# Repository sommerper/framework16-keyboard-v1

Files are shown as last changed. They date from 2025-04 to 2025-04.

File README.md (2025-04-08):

# Framework 16 Keyboard v1

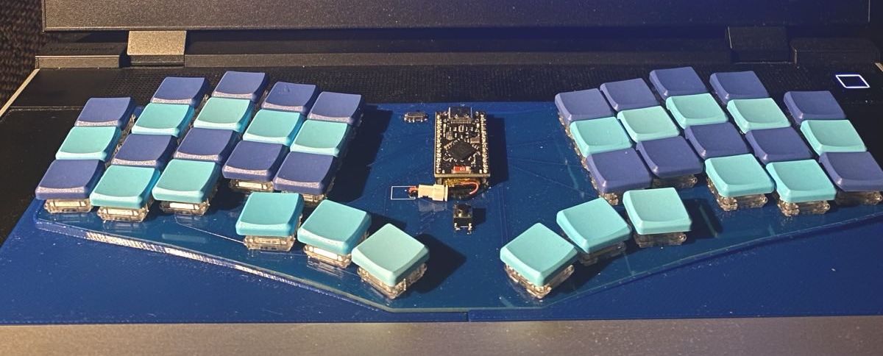
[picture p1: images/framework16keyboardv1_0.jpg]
Keyboard Image


Here's an ortholinear split keyboard that fits in your Framework 16 instead of the default keyboard.

It's using Kaihl Choc switches and the case has an angle of 5 degrees so it will not allow you to close the laptop while using it.

## ZMK and QMK

There some settings for zmk and qmk to get you started with the correct pin layout. The ZMK config is based on [Urob's config](https://github.com/urob/zmk-config)

Any Pro Micro compatible controller should work. The nice!nano v2 is used in the image, and I have also connected an RP2040 without any problems. 

## 3D Print Files
- Left and Right are for the laptop. They should have a tight fit without having to squeeze them in between the other components. 
- Bottom is for your desk so you can choose to put the pcb on your desk as well. It's possible to fit this on the build plate of a standard Prusa mk3s if you put it diagonally.
- Top is for travel protection. It fits on top of the Bottom case with the keyboard inside.

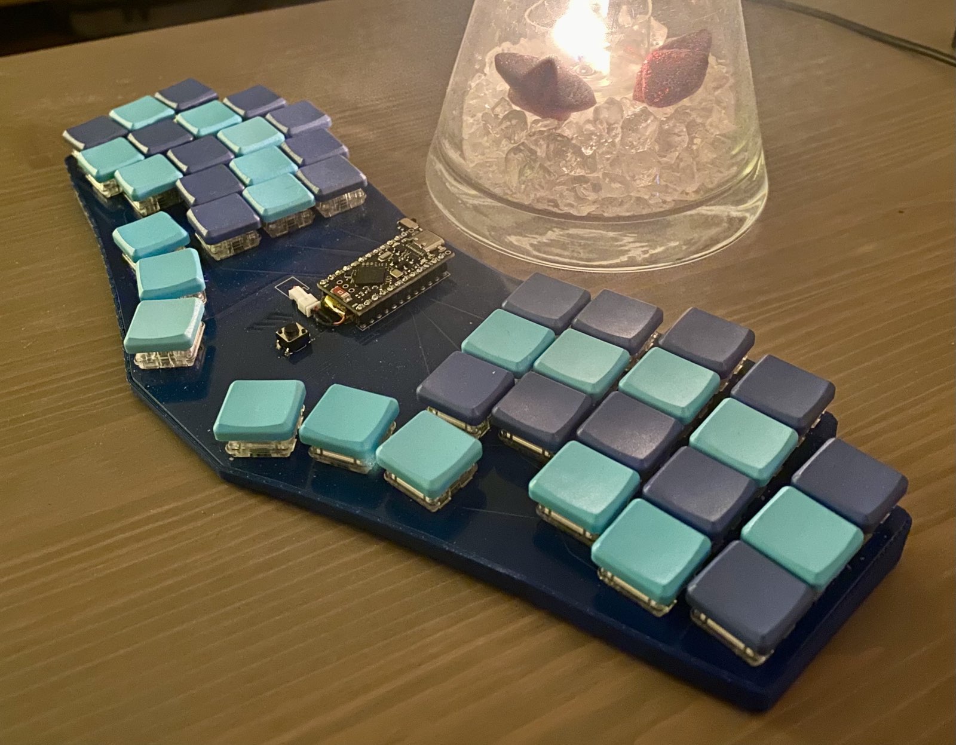
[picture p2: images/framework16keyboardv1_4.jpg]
Desk print


## ⚠️ Disclaimer

These PCB files are provided **as-is**, without any warranty or guarantee of functionality or safety. Use them at your own risk. I am not responsible for any damage, injury, or loss resulting from the use of these files.

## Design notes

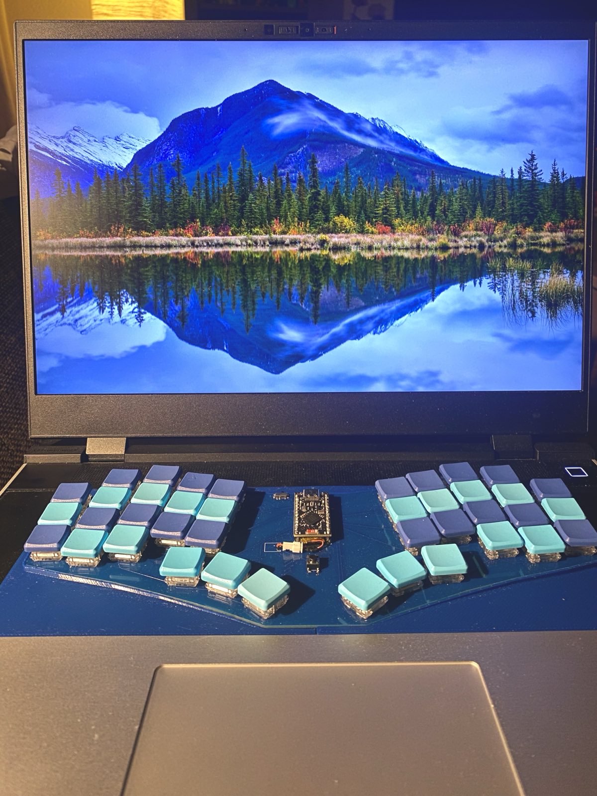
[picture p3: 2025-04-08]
images/framework16keyboardv1_1.jpg

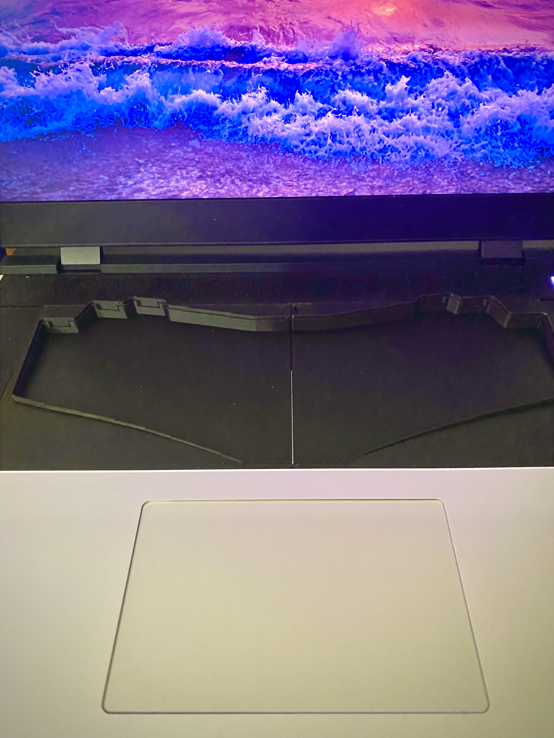
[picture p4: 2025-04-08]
images/framework16keyboardv1_3.jpg

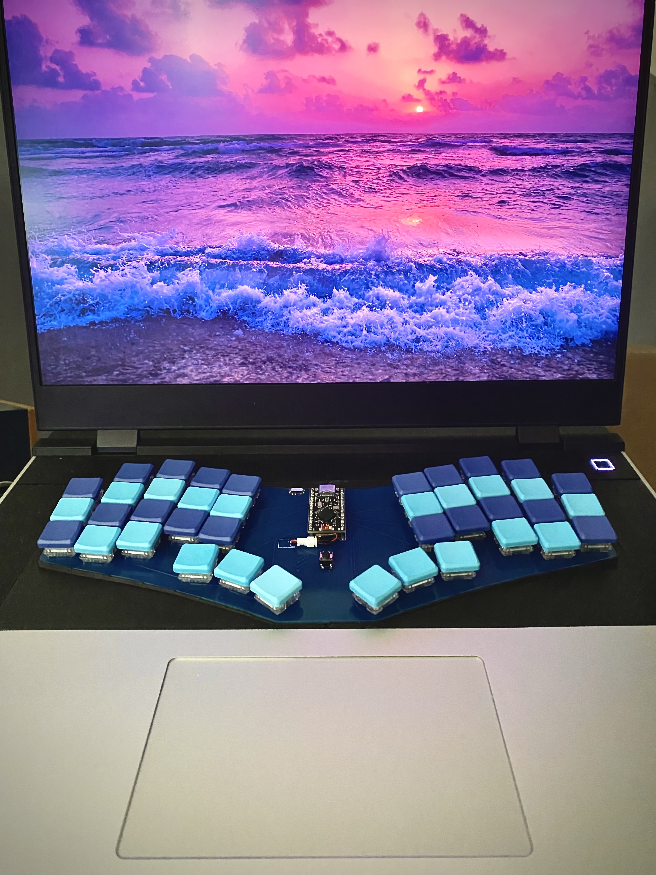
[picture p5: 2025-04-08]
images/framework16keyboardv1_2.jpg

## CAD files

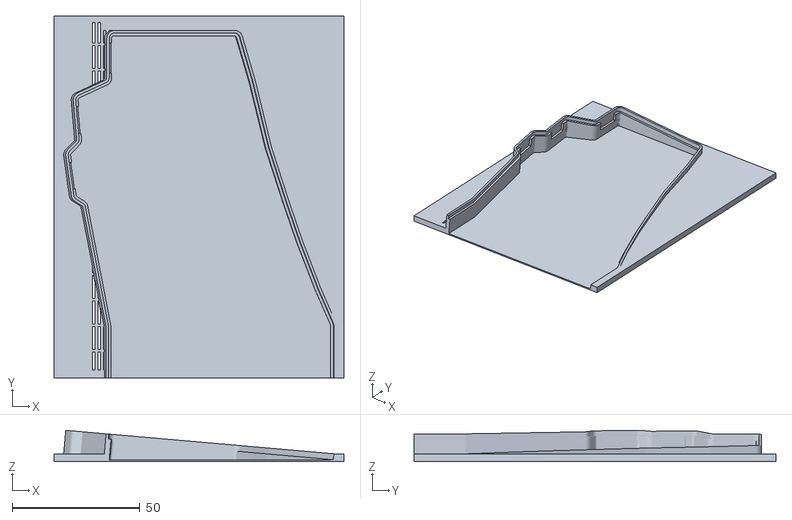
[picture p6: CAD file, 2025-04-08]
case/framework-16-keyboard-case-right.stl
113.4 x 141.7 x 12.3

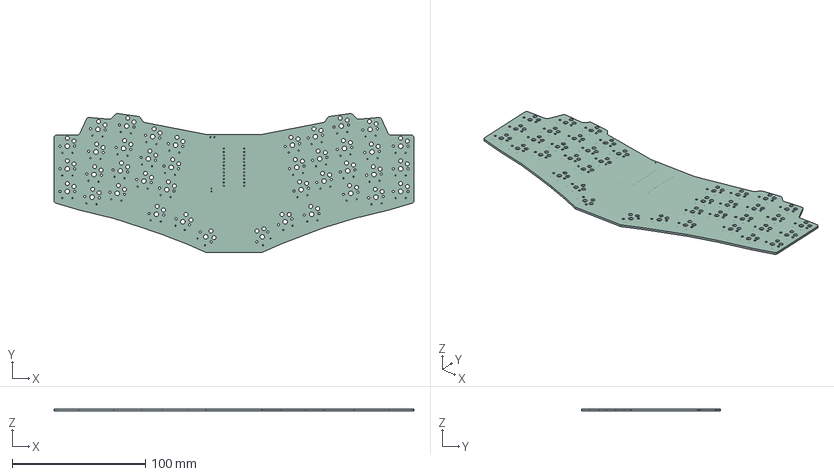
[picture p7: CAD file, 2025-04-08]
kicad/framework16v1/framework16v1.step
270.0 x 104.2 x 1.51 mm

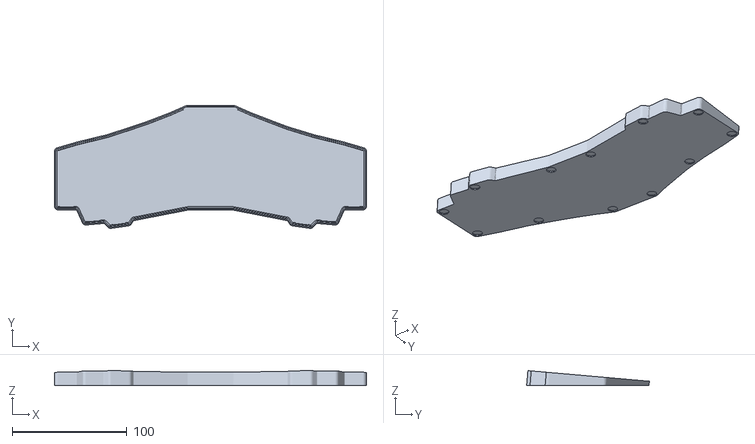
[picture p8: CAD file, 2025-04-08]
case/framework-16-keyboard-case-bottom.stl
272.2 x 107.2 x 12.9

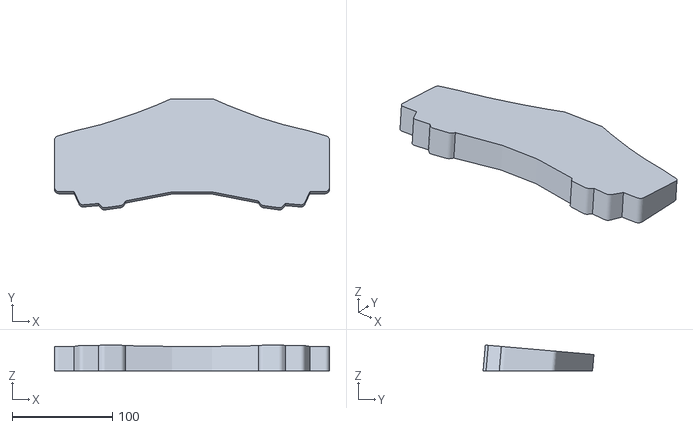
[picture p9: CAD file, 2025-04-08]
case/framework-16-keyboard-case-top.stl
274.8 x 110.9 x 25.9

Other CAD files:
case/framework-16-keyboard-case-left.stl

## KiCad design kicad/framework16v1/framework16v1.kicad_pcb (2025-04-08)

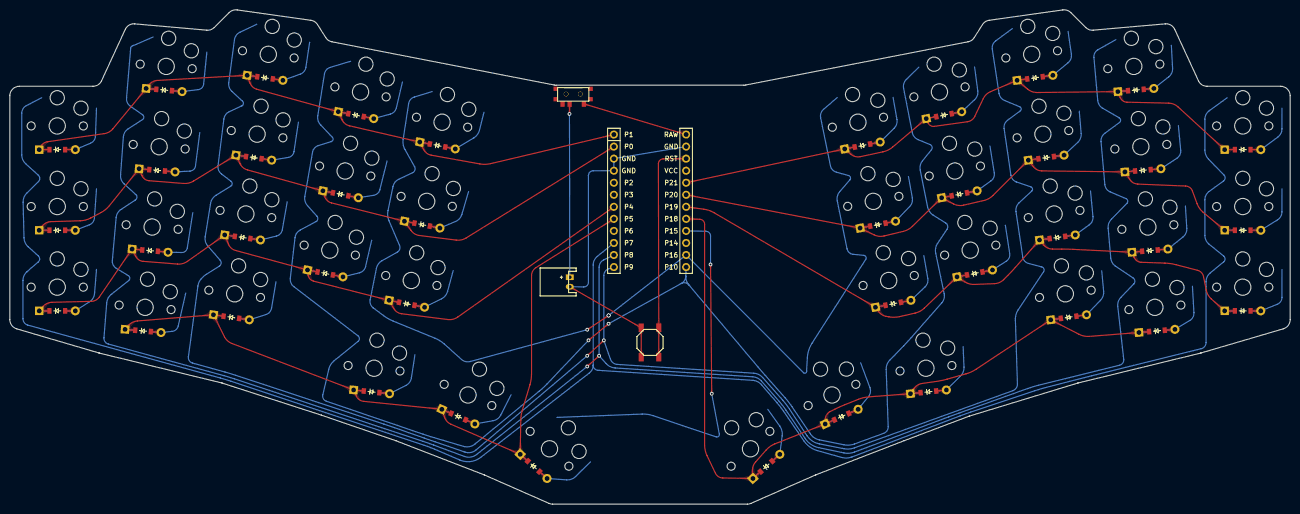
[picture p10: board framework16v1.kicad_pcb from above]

Board: 2 copper layers, 270.0 x 104.2 mm, 84 parts (0 on the bottom side), 58 nets.

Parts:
B1: SW_TACT_ALPS_SKQGABE010
D1, D2, D3, D4, D5, D6, D7, D8, D9, D10, D11, D12, D13, D14, D15, D16, D17, D18, D19, D20, D21, D22, D23, D24, D25, D26, D27, D28, D29, D30, D31, D32, D33, D34, D35, D36, D37, D38, D39, D40: ComboDiode
JST1: JST_PH_S2B-PH-K_02x2.00mm_Angled
MCU1: mcu_supermini_nrf52840
S1, S2, S3, S4, S5, S6, S7, S8, S9, S10, S11, S12, S13, S14, S15, S16, S17, S18, S19, S20, S21, S22, S23, S24, S25, S26, S27, S28, S29, S30, S31, S32, S33, S34, S35, S36, S37, S38, S39, S40: PG1350
T1: SPDT_C128955

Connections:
BAT: JST1.1, T1.2
GND: B1.1, JST1.2, MCU1.2, MCU1.21, MCU1.22
P0: D2.1, D6.1, D10.1, D13.1, D16.1, MCU1.23
P1: D3.1, D7.1, D11.1, D14.1, D17.1, MCU1.24
P4: D1.1, D5.1, D9.1, D12.1, D15.1, MCU1.18
P5: D4.1, D8.1, D18.1, D19.1, D20.1, MCU1.17
P7: MCU1.15, S1.1, S2.1, S3.1, S21.1, S22.1, S23.1
P8: MCU1.14, S4.1, S5.1, S6.1, S7.1, S24.1, S25.1, S26.1, S27.1
P9: MCU1.13, S8.1, S9.1, S10.1, S11.1, S28.1, S29.1, S30.1, S31.1
P10: MCU1.12, S12.1, S13.1, S14.1, S18.1, S32.1, S33.1, S34.1, S38.1
P15: MCU1.9, S20.1, S40.1
P16: MCU1.11, S15.1, S16.1, S17.1, S19.1, S35.1, S36.1, S37.1, S39.1
P18: D24.1, D28.1, D38.1, D39.1, D40.1, MCU1.8
P19: D21.1, D25.1, D29.1, D32.1, D35.1, MCU1.7
P20: D22.1, D26.1, D30.1, D33.1, D36.1, MCU1.6
P21: D23.1, D27.1, D31.1, D34.1, D37.1, MCU1.5
RAW: MCU1.1, T1.1
RST: B1.2, MCU1.3
far_thumb: D20.2, S20.2
home_thumb: D19.2, S19.2
index_home: D12.2, S12.2
index_num: D14.2, S14.2
index_top: D13.2, S13.2
inner_home: D15.2, S15.2
inner_num: D17.2, S17.2
inner_top: D16.2, S16.2
middle_bottom: D8.2, S8.2
middle_home: D9.2, S9.2
middle_num: D11.2, S11.2
middle_top: D10.2, S10.2
mirror_far_thumb: D40.2, S40.2
mirror_home_thumb: D39.2, S39.2
mirror_index_home: D32.2, S32.2
mirror_index_num: D34.2, S34.2
mirror_index_top: D33.2, S33.2
mirror_inner_home: D35.2, S35.2
mirror_inner_num: D37.2, S37.2
mirror_inner_top: D36.2, S36.2
mirror_middle_bottom: D28.2, S28.2
mirror_middle_home: D29.2, S29.2
mirror_middle_num: D31.2, S31.2
mirror_middle_top: D30.2, S30.2
mirror_near_thumb: D38.2, S38.2
mirror_pinky_home: D21.2, S21.2
mirror_pinky_num: D23.2, S23.2
mirror_pinky_top: D22.2, S22.2
mirror_ring_bottom: D24.2, S24.2
mirror_ring_home: D25.2, S25.2
mirror_ring_num: D27.2, S27.2
mirror_ring_top: D26.2, S26.2
near_thumb: D18.2, S18.2
pinky_home: D1.2, S1.2
pinky_num: D3.2, S3.2
pinky_top: D2.2, S2.2
ring_bottom: D4.2, S4.2
ring_home: D5.2, S5.2
ring_num: D7.2, S7.2
ring_top: D6.2, S6.2
